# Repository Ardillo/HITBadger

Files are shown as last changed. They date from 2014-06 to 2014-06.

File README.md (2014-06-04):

##The Hack In The Box (HITB) 2014 Amsterdam Badge
Also known as: <i>"HITBadger"</i> --> http://www.randomdata.nl/wiki/index.php/HITBadger <br>

Based on an arduino UNO with ATmega328.<br>
Goal is to have only through hole components so everybody can make one.<br>

We've used schematics from the Arduino Uno from Aruino.cc, 
Diavolino by Evil Mad Science and BoArduino by Adafruit.

We changed some default settings in the MIRF library to fit our needs.
Therefor we call it "HITBmirf" for example it uses 32 byte payloads as default.<br>
The NRF24L01+ could also used with the RF24 library from maniacbug and the standard MIRF 
library Look here for a good tutorial:<br>
http://maniacbug.wordpress.com/2011/11/02/getting-started-rf24/ <br>
His github can be cloned and used directly after copying the files to the
correct directory in your arduino installation.
https://github.com/maniacbug/RF24/ <br>

Build working concept with the "GettingStarted" program. I measured the power
consumption at 4.7V. it was 23mA. 
This could be enhanced by using a different library which puts the Arduino to
sleep, see: http://www.openhomeautomation.net/arduino-battery/ <br>
The power circuit seemed quite stable.

The HITBadger.zip contains all necessary Gerber files, 10 in total. 
Smart-prototyping needs 10 files, no offset, no mirror, no rotate, no upside
down. (http://smart-prototyping.com/PCB-Prototyping.html) <br>

##Arduino IDE
The board is completely programmable within the Arduino IDE. Therefor you need to copy the files 
of the <i>libraries</i> and <i>hardware</i> folder to the according folder of the Arduino IDE install folder.
The location of those folder varies depending on the OS you're using. A quick search on the internetzz will give 
you more information.
###Examples
We've included all the used programs during the event in the examples of our HITBmirf library, when 
imported correctly you can access them through the menu of your Arduino IDE.
A short explanation for the programs used in the event:
* HITBadgeClient <br>
The program everyone got on their personal badge with their nickname acting as a address.
* HITBadgeCommStation<br>
The program used on the base stations which where sending messages to the personal badges.
* HITBadgeCommSend -Receive <br>
Some testing code
* HITBadgeComStationParty<br>
The program used on the base stations during the after party to send everyone a message.
* HITBadgeLEDRoutine
A +/- 70 seconds during program which do all kinds of animations with the LED's.

###Hardware
Some of you have a ATmega328 and others have a ATmega328p both of the chips have the same pinout, but
when flashing a new bootloader (if you ever going to do so) you need some changements in your IDE.
If you copy the files of the <i> hardware</i> folder to the according location of your IDE you will notice
that two new options are available in the boards menu of the Arduino IDE. (Tools -> Board).
One of them is specific for uploading a new Arduino bootloader to a HITBadge with a ATmega328 (without the p).

##FTDI without DTR line
To use a FTDI uploader without a DTR line add a line to your preferences.txt of your Arduino IDE
<br>
<code>
upload.verbose = true
</code><br>
When the main init is started while uploading your code press the reset button to start the
bootloader of the Arduino again and upload your code. This takes some practice.
source: https://electronics.stackexchange.com/questions/2512/ftdi-basic-breakout-5v
<br>

Some url's to get you going:<br>
* https://learn.sparkfun.com/tutorials/how-to-install-and-setup-eagle/download-install-run<br>
* https://learn.sparkfun.com/tutorials/using-eagle-schematic/<br>
* https://learn.sparkfun.com/tutorials/using-eagle-board-layout/<br>
* https://learn.sparkfun.com/tutorials/making-custom-footprints-in-eagle/<br>
* https://learn.sparkfun.com/tutorials/designing-pcbs-smd-footprints/<br>
* http://arduino.cc/en/uploads/Hacking/Atmega168PinMap2.png<br>
* http://learn.adafruit.com/boarduino-kits<br>
* http://learn.adafruit.com/downloads/pdf/boarduino-kits.pdf<br>
* http://learn.adafruit.com/system/assets/assets/000/010/223/original/boarduinosch.png<br>
* https://www.adafruit.com/partfinder/<br>
* http://wiki.evilmadscientist.com/Diavolino<br>
* https://s3.amazonaws.com/evilmadscience/KitInstrux/diavolino_instrux.pdf<br>
* https://s3.amazonaws.com/evilmadscience/KitInstrux/diavolino_schematic.pdf<br>

####NRF24L01 specific URL's:
* http://arduino-info.wikispaces.com/Nrf24L01-2.4GHz-HowTo
* http://hack.lenotta.com/arduino-nrf24l01-modules-testing/
* http://maniacbug.wordpress.com/2011/11/02/getting-started-rf24/
* http://yourduino.com/docs/nRF24L01-Modules-connection-diagram.pdf
* http://playground.arduino.cc/InterfacingWithHardware/Nrf24L01

####Bill of "difficult" Materials (BOdM):
* http://nl.farnell.com/microchip/mcp1700-3302e-to/ic-v-reg-ldo-250ma-to-92-3/dp/1296588
* http://nl.farnell.com/microchip/mcp1702-5002e-to/ic-v-reg-ldo-250ma-to-92-3/dp/1331487
* http://nl.farnell.com/txc/9b-16-000meej-b/xtal-16-000mhz-18pf-hc-49s/dp/1842217<br>

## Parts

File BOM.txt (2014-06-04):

Partlist exported from /home/ardillo/eagle/ownprojects/HITBadger/v0.1.sch at 3/24/14 9:44 PM

Part          Value           Device           Package          Description                                        MF MPN OC_FARNELL OC_NEWARK POWER_JUMPER PROD_ID  
ANALOG                        M06LOCK          1X06_LOCK        Header 6                                                                                             
C1            0.1uF           CAPPTH           CAP-PTH-SMALL    Capacitor                                                                                            
C2            0.1uF           CAPPTH           CAP-PTH-SMALL    Capacitor                                                                                            
C7            18pF            CAPPTH           CAP-PTH-SMALL    Capacitor                                                                                            
C8            0.1uF           CAPPTH           CAP-PTH-SMALL    Capacitor                                                                                            
C9            0.1uF           CAPPTH           CAP-PTH-SMALL    Capacitor                                                                                            
C10           18pF            CAPPTH           CAP-PTH-SMALL    Capacitor                                                                                            
C11           0.1uF           CAPPTH           CAP-PTH-SMALL    Capacitor                                                                                            
C13           0.1uF           CAPPTH           CAP-PTH-SMALL    Capacitor                                                                                            
C14           0.1uF           CAPPTH           CAP-PTH-SMALL    Capacitor                                                                                            
D2            1N4004          1N4004           DO41-10          DIODE                                                                                                
DIGITAL_PINS1                 M08LOCK          1X08_LOCK        Header 8                                                                                             
DIGITAL_PINS2                 M08LOCK          1X08_LOCK        Header 8                                                                                             
FRAME1        FRAME-LETTER    FRAME-LETTER     CREATIVE_COMMONS Schematic Frame                                                                                      
J2            AVR_SPI         AVR_SPI_PRG_6PTH 2X3              AVR ISP 6 Pin                                                                                        
J3            POWER_JACKPTH   POWER_JACKPTH    POWER_JACK_PTH   Power Jack                                                                                  PRT-00119
JP1           FTDI_DEVICE     FTDI_DEVICE      FTDI_DEVICE_SIDE Connector which mates to FTDI basic or FTDI cable.                                                   
MCP1700-3.3V                  MCP1700INLINE    TO92-INLINE      VOLTAGE REGULATOR                                                                                    
MCP1702-5V                    MCP1700INLINE    TO92-INLINE      VOLTAGE REGULATOR                                                                                    
NRF           NRF24L01+       NRF24L01+        2X4              .1" header, two rows of four.                                                                        
ON                            LED3MM           LED3MM           LEDs                                                                                                 
P3                            LED5MM           LED5MM           LEDs                                                                                                 
P5                            LED5MM           LED5MM           LEDs                                                                                                 
P6                            LED5MM           LED5MM           LEDs                                                                                                 
P9                            LED5MM           LED5MM           LEDs                                                                                                 
P13                           LED3MM           LED3MM           LEDs                                                                                                 
POWER                         M05LOCK          1X05_LOCK        Header 5                                                                                             
PWR_JMPR                      M03LOCK          1X03_LOCK        Header 3                                                                                             
Q1            16MHz           CRYSTALHC49S     HC49/S           CRYSTAL                                                   1667008    unknown                         
R1            330             RESISTORPTH-1/4W AXIAL-0.4        Resistor                                                                                             
R2            330             RESISTORPTH-1/4W AXIAL-0.4        Resistor                                                                                             
R3            330             RESISTORPTH-1/4W AXIAL-0.4        Resistor                                                                                             
R4            10K             RESISTORPTH-1/4W AXIAL-0.4        Resistor                                                                                             
R5            330             RESISTORPTH-1/4W AXIAL-0.4        Resistor                                                                                             
R7            330             RESISTORPTH-1/4W AXIAL-0.4        Resistor                                                                                             
R8            1.0K            RESISTORPTH-1/4W AXIAL-0.4        Resistor                                                                                             
S1                            TAC_SWITCHPTH    TACTILE-PTH      Momentary Switch                                                                                     
U2            ATMEGA328P_PDIP ATMEGA328P_PDIP  DIL28-3          uC used in the Arduino

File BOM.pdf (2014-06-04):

Sheet1

part | package | amount | price pp | total price
1N4004 | DO41-10 | 1 | € 0.22 | € 0.22 | 9956109
MCP1700-3.3V | TO92-INLINE | 1 | € 0.32 | € 0.32 | | 1296588
MCP1702-5V | TO92-INLINE | 1 | € 0.40 | € 0.40 | | 1331487
ATMEGA328P | DIL28-3 | 1 | € 3.09 | € 3.09 | 1715487
crystal 16MHz | HC49/S | 1 | € 0.44 | € 0.44 | 1842217
| CAP-PTH-SMALL | 7 | € 0.12 | € 0.83 | | 1457655
capacitor 22pF | CAP-PTH-SMALL | 2 | € 0.24 | € 0.47 | | 1216407
resistor 10K Ohm AXIAL-0.4 | | 1 | € 0.09 | € 0.09 | | 9341110
resistor 1K Ohm | AXIAL-0.4 | 1 | € 0.09 | € 0.09 | 9341102
resistor 330 Ohm AXIAL-0.4 | | 5 | € 0.09 | € 0.44 | | 9341730
led 3mm red | 3MM | 2 | € 0.22 | € 0.45 | 2217957
led 5mm red | 5MM clear 35MCD | 4 | € 0.25 | € 1.00 | | 4912445
| TACTILE-PTH | 1 | € 0.25 | € 0.25 | | 9471723
header 6 pins | 90 degree male (FTDI) | 1 | € 1.18 | € 1.18 | | 9733477
header SPI (2x3) | male | 1 | € 0.38 | € 0.38 | 1593440
header 3 pins | power jumper head. | 1 | € 0.20 | € 0.20 | | 1248141
jumper | power jumper | 1 | € 0.46 | € 0.46 | | 4218152
EXTRA: | +++ | +++ | +++ | +++ | +++ | +++
header 8 pins | female | 2 | € 0.87 | € 1.74 | 1593463
header 6 pins | female | 1 | € 1.00 | € 1.00 | 1593462
header 5 pins | female | 1 | € 1.02 | € 1.02 | 1593461
| | 1 | € 0.90 | € 0.90 | | 1217037
NRF24L01+ | 1 | € 1.00 | € 1.00 | EBAY
| | | | € 10.29
| | | | € 15.95 Total price for 1 with all components
| | | | € 8.17
| | | | € 11.20 Total price for 1 (order of 100) with all components
url | artikelnr
http://nl.farnell.com/jsp/search/productdetail.jsp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
capacitor 0.1 uF | http://nl.farnell.com/kemet/c320c104k5r5ta/cap-mlcc-x7r-100nf-50v-rad/dp/1457655
http://nl.farnell.com/multicomp/mcrr25220cogj0200/cap-cer-c0g-np0-22pf-200v-rad/dp/1216407http://nl.farnell.com/multicomp/mf25-10k/resistor-10k-0-25w-1/dp/9341110?SK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
pcb button tactile | http://nl.farnell.com/multicomp/mcdts6-3k/switch-spst-0-05a-12vdc-tht/dp/9471723
http://nl.farnell.com/molex/90121-0766/header-right-angle-1row-6way/dp/9733477http://nl.farnell.com/multicomp/2213s-06g/header-2-row-vert-6way/dp/1593440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

http://nl.farnell.com/multicomp/2212s-08sg-85/socket-pcb-1-row-8way/dp/1593463http://nl.farnell.com/multicomp/2212s-06sg-85/socket-pcb-1-row-6way/dp/1593462http://nl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
powerjack? | http://nl.farnell.com/lumberg/neb-21-r/socket-low-voltage-2-1mm-4a/dp/1217037?Ntt=1217037

Total price for 1 without female headers and powerjack

Total price for 1 (order of 100) without female headers and powerjack

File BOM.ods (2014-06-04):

part | package | amount | price pp | total price | url | artikelnr
1N4004 | DO41-10 | 1 | € 0.22 | € 0.22 | http://nl.farnell.com/jsp/search/productdetail.jsp?SKU=9556109 | 9956109
MCP1700-3.3V | TO92-INLINE | 1 | € 0.32 | € 0.32 | http://nl.farnell.com/microchip/mcp1700-3302e-to/ic-v-reg-ldo-250ma-to-92-3/dp/1296588 | 1296588
MCP1702-5V | TO92-INLINE | 1 | € 0.40 | € 0.40 | http://nl.farnell.com/microchip/mcp1702-5002e-to/ic-v-reg-ldo-250ma-to-92-3/dp/1331487 | 1331487
ATMEGA328P | DIL28-3 | 1 | € 3.09 | € 3.09 | http://nl.farnell.com/atmel/atmega328p-pu/mcu-8bit-avr-32k-flash-28pdip/dp/1715487 | 1715487
crystal 16MHz | HC49/S | 1 | € 0.44 | € 0.44 | http://nl.farnell.com/txc/9b-16-000meej-b/xtal-16-000mhz-18pf-hc-49s/dp/1842217 | 1842217
capacitor 0.1 uF | CAP-PTH-SMALL | 7 | € 0.12 | € 0.83 | http://nl.farnell.com/kemet/c320c104k5r5ta/cap-mlcc-x7r-100nf-50v-rad/dp/1457655 | 1457655
capacitor 22pF | CAP-PTH-SMALL | 2 | € 0.24 | € 0.47 | http://nl.farnell.com/multicomp/mcrr25220cogj0200/cap-cer-c0g-np0-22pf-200v-rad/dp/1216407 | 1216407
resistor 10K Ohm | AXIAL-0.4 | 1 | € 0.09 | € 0.09 | http://nl.farnell.com/multicomp/mf25-10k/resistor-10k-0-25w-1/dp/9341110?Ntt=9341110 | 9341110
resistor 1K Ohm | AXIAL-0.4 | 1 | € 0.09 | € 0.09 | http://nl.farnell.com/multicomp/mf25-1k/resistor-1k-0-25w-1/dp/9341102?Ntt=9341102 | 9341102
resistor 330 Ohm | AXIAL-0.4 | 5 | € 0.09 | € 0.44 | http://nl.farnell.com/multicomp/mf25-330r/resistor-330r-0-25w-1/dp/9341730?Ntt=9341730 | 9341730
led 3mm red | 3MM | 2 | € 0.22 | € 0.45 | http://nl.farnell.com/kingbright/l-934id-5v/led-resistor-3mm-red-5v/dp/2217957?Ntt=2217957 | 2217957
led 5mm red | 5MM clear 35MCD | 4 | € 0.25 | € 1.00 | http://nl.farnell.com/jsp/search/productdetail.jsp?SKU=4912445 | 4912445
pcb button tactile | TACTILE-PTH | 1 | € 0.25 | € 0.25 | http://nl.farnell.com/multicomp/mcdts6-3k/switch-spst-0-05a-12vdc-tht/dp/9471723 | 9471723
header 6 pins | 90 degree male (FTDI) | 1 | € 1.18 | € 1.18 | http://nl.farnell.com/molex/90121-0766/header-right-angle-1row-6way/dp/9733477 | 9733477
header SPI (2x3) | male | 1 | € 0.38 | € 0.38 | http://nl.farnell.com/multicomp/2213s-06g/header-2-row-vert-6way/dp/1593440?Ntt=1593440 | 1593440
header 3 pins | power jumper head. | 1 | € 0.20 | € 0.20 | http://nl.farnell.com/te-connectivity-amp/826926-3/connector-header-tht-2-54mm-3way/dp/1248141 | 1248141
jumper | power jumper | 1 | € 0.46 | € 0.46 | http://nl.farnell.com/te-connectivity-amp/0-0142270-3/jumper-amp-modu-black-tinned/dp/4218152 | 4218152
EXTRA: | +++ | +++ | +++ | +++ | +++ | +++
header 8 pins | female | 2 | € 0.87 | € 1.74 | http://nl.farnell.com/multicomp/2212s-08sg-85/socket-pcb-1-row-8way/dp/1593463 | 1593463
header 6 pins | female | 1 | € 1.00 | € 1.00 | http://nl.farnell.com/multicomp/2212s-06sg-85/socket-pcb-1-row-6way/dp/1593462 | 1593462
header 5 pins | female | 1 | € 1.02 | € 1.02 | http://nl.farnell.com/multicomp/2212s-05sg-85/socket-pcb-1-row-5way/dp/1593461 | 1593461
powerjack? |  | 1 | € 0.90 | € 0.90 | http://nl.farnell.com/lumberg/neb-21-r/socket-low-voltage-2-1mm-4a/dp/1217037?Ntt=1217037 | 1217037
NRF24L01+ |  | 1 | € 1.00 | € 1.00 | EBAY
 |  |  |  | € 10.29 | Total price for 1 without female headers and powerjack
 |  |  |  | € 15.95 | Total price for 1 with all components
 |  |  |  | € 8.17 | Total price for 1 (order of 100) without female headers and powerjack
 |  |  |  | € 11.20 | Total price for 1 (order of 100) with all components

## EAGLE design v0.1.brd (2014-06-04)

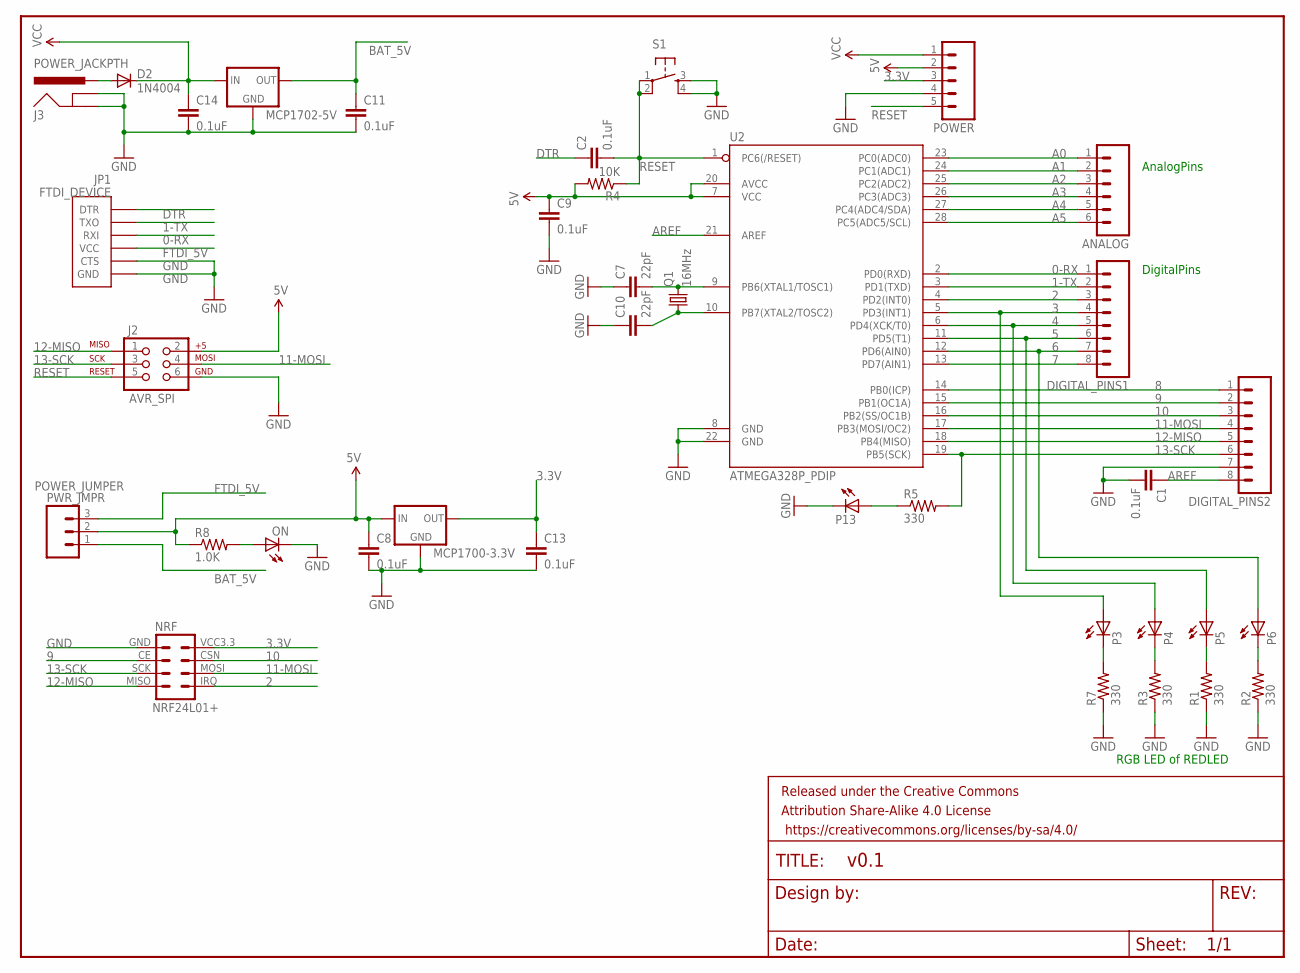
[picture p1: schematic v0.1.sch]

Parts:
ANALOG: M06LOCK; 1X06_LOCK
C1, C2, C8, C9, C11, C13, C14: 0.1uF; CAP-PTH-SMALL
C7, C10: 22pF; CAP-PTH-SMALL
D2: 1N4004; DO41-10
DIGITAL_PINS1, DIGITAL_PINS2: M08LOCK; 1X08_LOCK
FRAME1: FRAME-LETTER; CREATIVE_COMMONS
J2: AVR_SPI; 2X3
J3: POWER_JACKPTH; POWER_JACK_PTH
JP1: FTDI_DEVICE; FTDI_DEVICE_SIDE
MCP1700-3.3V, MCP1702-5V: MCP1700INLINE; TO92-INLINE
NRF: NRF24L01+; 2X4
ON: LED3MM
P3, P4, P5, P6: LED5MM
P13: LED3MM
POWER: M05LOCK; 1X05_LOCK
PWR_JMPR: M03LOCK; 1X03_LOCK
Q1: 16MHz; HC49/S
R1, R2, R3, R5, R7: 330; AXIAL-0.4
R4: 10K; AXIAL-0.4
R8: 1.0K; AXIAL-0.4
S1: TAC_SWITCHPTH; TACTILE-PTH
U2: ATMEGA328P_PDIP; DIL28-3

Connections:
0-RX: DIGITAL_PINS1.1, JP1.P$3 (RXI), U2.2 (PD0(RXD))
1-TX: DIGITAL_PINS1.2, JP1.P$2 (TXO), U2.3 (PD1(TXD))
2: DIGITAL_PINS1.3, NRF.IRQ, U2.4 (PD2(INT0))
3: DIGITAL_PINS1.4, P3.A, U2.5 (PD3(INT1))
3.3V: C13.1, MCP1700-3.3V.3 (OUT), NRF.VCC3.3 (VCC), POWER.3
4: DIGITAL_PINS1.5, P4.A, U2.6 (PD4(XCK/T0))
5: DIGITAL_PINS1.6, P5.A, U2.11 (PD5(T1))
5V: C8.1, C9.1, J2.2, MCP1700-3.3V.2 (IN), POWER.2, PWR_JMPR.2, R4.P$2 (2), R8.P$1 (1), U2.7 (VCC), U2.20 (AVCC)
6: DIGITAL_PINS1.7, P6.A, U2.12 (PD6(AIN0))
7: DIGITAL_PINS1.8, U2.13 (PD7(AIN1))
8: DIGITAL_PINS2.1, U2.14 (PB0(ICP))
9: DIGITAL_PINS2.2, NRF.CE, U2.15 (PB1(OC1A))
10: DIGITAL_PINS2.3, NRF.CSN, U2.16 (PB2(SS/OC1B))
11-MOSI: DIGITAL_PINS2.4, J2.4, NRF.MOSI, U2.17 (PB3(MOSI/OC2))
12-MISO: DIGITAL_PINS2.5, J2.1, NRF.MISO, U2.18 (PB4(MISO))
13-SCK: DIGITAL_PINS2.6, J2.3, NRF.SCK, R5.P$2 (2), U2.19 (PB5(SCK))
A0: ANALOG.1, U2.23 (PC0(ADC0))
A1: ANALOG.2, U2.24 (PC1(ADC1))
A2: ANALOG.3, U2.25 (PC2(ADC2))
A3: ANALOG.4, U2.26 (PC3(ADC3))
A4: ANALOG.5, U2.27 (PC4(ADC4/SDA))
A5: ANALOG.6, U2.28 (PC5(ADC5/SCL))
AREF: C1.1, DIGITAL_PINS2.8, U2.21 (AREF)
B: P5.K (C), R1.P$2 (2)
B1: P3.K (C), R7.P$2 (2)
BAT_5V: C11.1, MCP1702-5V.3 (OUT), PWR_JMPR.1
DTR: C2.1, JP1.P$1 (DTR)
FTDI_5V: JP1.P$4 (VCC), PWR_JMPR.3
GND: C1.2, C7.1, C8.2, C9.2, C10.1, C11.2, C13.2, C14.2, DIGITAL_PINS2.7, J2.6, J3.GND, J3.GNDBREAK, JP1.P$5 (CTS), JP1.P$6 (GND), MCP1700-3.3V.1 (GND), MCP1702-5V.1 (GND), NRF.GND, ON.K (C), P13.K (C), POWER.4, R1.P$1 (1), R2.P$1 (1), R3.P$1 (1), R7.P$1 (1), S1.3, S1.4, U2.8 (GND), U2.22 (GND)
unnamed: ON.A, R8.P$2 (2)
unnamed: P13.A, R5.P$1 (1)
unnamed: C10.2, Q1.1, U2.10 (PB7(XTAL2/TOSC2))
unnamed: C7.2, Q1.2, U2.9 (PB6(XTAL1/TOSC1))
unnamed: D2.A, J3.PWR
unnamed: P4.K (C), R3.P$2 (2)
unnamed: P6.K (C), R2.P$2 (2)
RESET: C2.2, J2.5, POWER.5, R4.P$1 (1), S1.1, S1.2, U2.1 (PC6(/RESET))
VCC: C14.1, D2.C, MCP1702-5V.2 (IN), POWER.1

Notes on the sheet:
RGB LED of REDLED
AnalogPins
DigitalPins

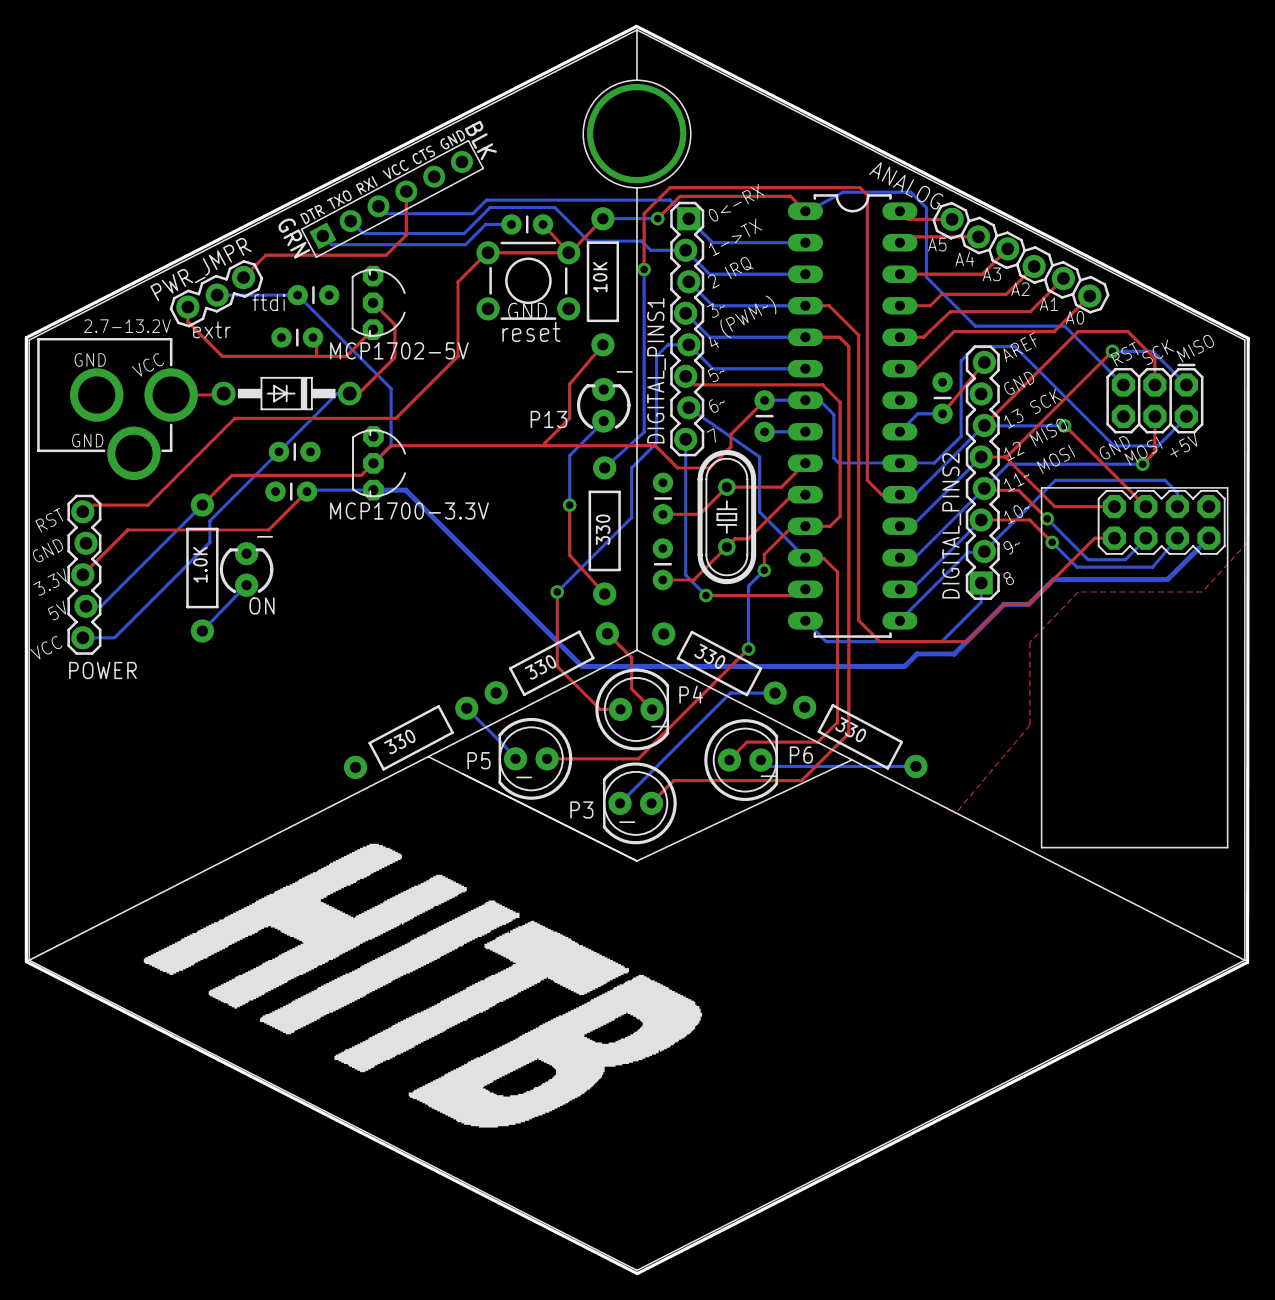
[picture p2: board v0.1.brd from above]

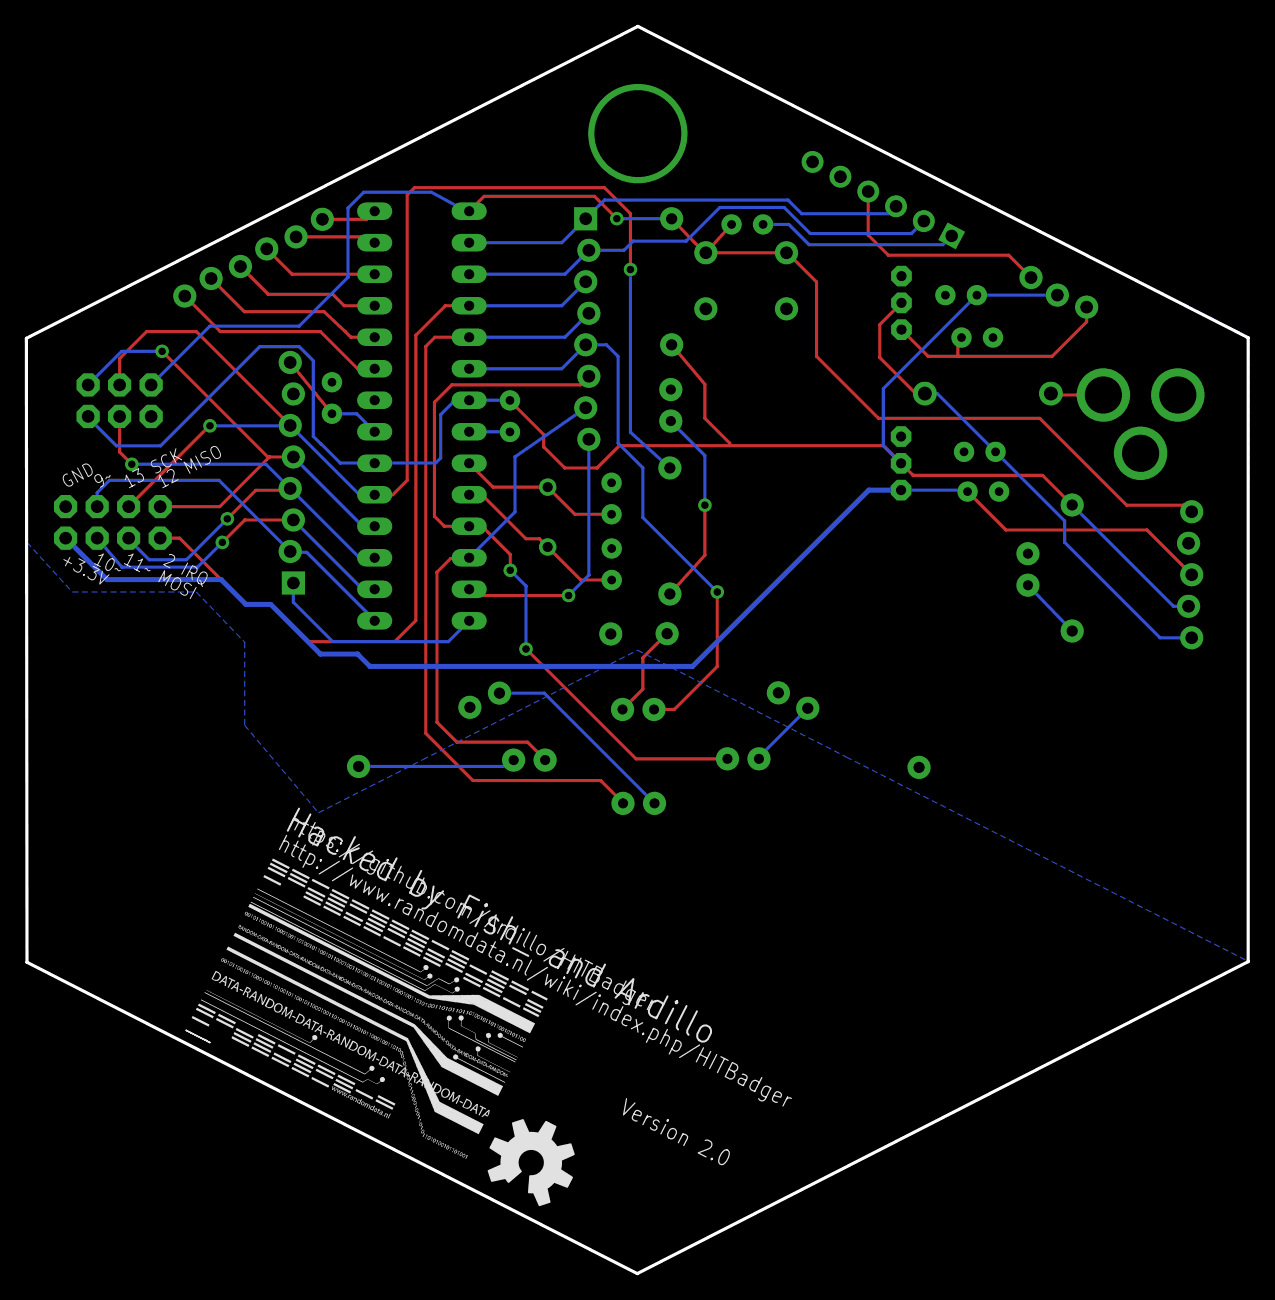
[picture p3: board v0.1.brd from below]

Board: 2 copper layers, 98.5 x 100.5 mm, 43 parts (3 on the bottom side), 38 nets.

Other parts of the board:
U$1: HITB_LOGO
U$2: HITB
U$3: OSHW-LOGO-L
U$4: OSHWLOGO_0.3
U$6: RANDOMDATA_LOGO_M

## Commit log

2014-06-04 Update after event
    [BOM.ods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]
2015-05-28 Adding Arduino 1.5.1 and above support.
    As of 1.5.1 you have to define an upload tool. This was tested on 1.6.3.
2015-05-28 Continuous mode client badge
    Slight change and cleanup to the client code. It will now run
    continuously until it gets a new update. You can still reset it to stop
    the current pattern.
2015-05-29 Arduino board manager install file
    This is needed for the arduino board manager.
2015-05-29 Json file for the Arduino Boards manager
    Needed for automated installation as of 1.6.4

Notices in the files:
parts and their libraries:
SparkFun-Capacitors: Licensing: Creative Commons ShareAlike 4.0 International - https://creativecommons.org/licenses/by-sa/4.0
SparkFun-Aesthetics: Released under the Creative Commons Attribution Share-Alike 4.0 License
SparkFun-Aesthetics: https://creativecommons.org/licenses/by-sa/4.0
